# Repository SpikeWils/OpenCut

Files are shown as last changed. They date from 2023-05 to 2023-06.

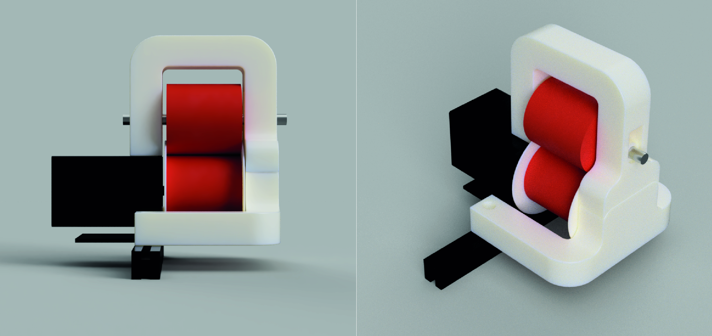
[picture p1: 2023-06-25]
OpenCut Src & Docs/OpenCut Docs/3D Printing Files/Feed Motor Assembly Renders.jpg

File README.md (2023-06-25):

# OpenCut

OpenCut is an open-source project aimed at developing an automated cable processing machine. It is designed to measure, cut cables to length, and print a cable ID directly onto the cable. Currently, the project is in its infancy, and only a prototype machine has been constructed. However, the project has the vision to continue development and cultivate a flexible and innovative solution to automated cable processing for wiring looms and harnesses. The intent is to foster a community to contribute to and further the development of the project.

The project includes two main components: MAS (Manufacturing Automation Software) and Machine Software.

## Directory Structure

The repository is divided into two main directories: `OpenCut Src` and `OpenCut Docs`.

### Source Code

The `OpenCut Src` directory contains the source code of the project and is divided into two sub-directories:

- `OpenCut MAS Software`: This directory contains the code for the MAS component of the OpenCut project. The MAS is the interface between the operator and the machine, allowing data about different cable types to be added, stored, modified, etc. It also saves machine parameters. It is designed to be executed on a desktop computer but can also be run on an SBC like a Raspberry Pi.
- `OpenCut Machine Software`: This directory contains the code for the Machine software component of the OpenCut project. This software is to be flashed onto the microcontroller embedded in the OpenCut machine.

### Documentation

The `OpenCut Docs` directory contains various forms of documentation and resources related to the project, including:

- `3D Printing Files`: This directory contains files related to 3D printing parts for the OpenCut project.
- `Functional Flow Charts`: This directory contains flowcharts that explain the functional flow of the OpenCut hardware and software.
- `Laser Cutting Files`: This directory contains files related to laser cutting parts for the OpenCut project.
- `Schematics`: This directory contains schematics related to the OpenCut project.

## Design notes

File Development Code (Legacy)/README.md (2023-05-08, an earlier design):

# Cable Machine
 
Abbreviations
-------------------------
  FM = Feed Motor
  CM = Cut Motor
  ENA = Enable
  DIR = Direction
  PUL = Pulse (A.K.A Step)
  CW = Clockwise
  CCW = Counter Clockwise

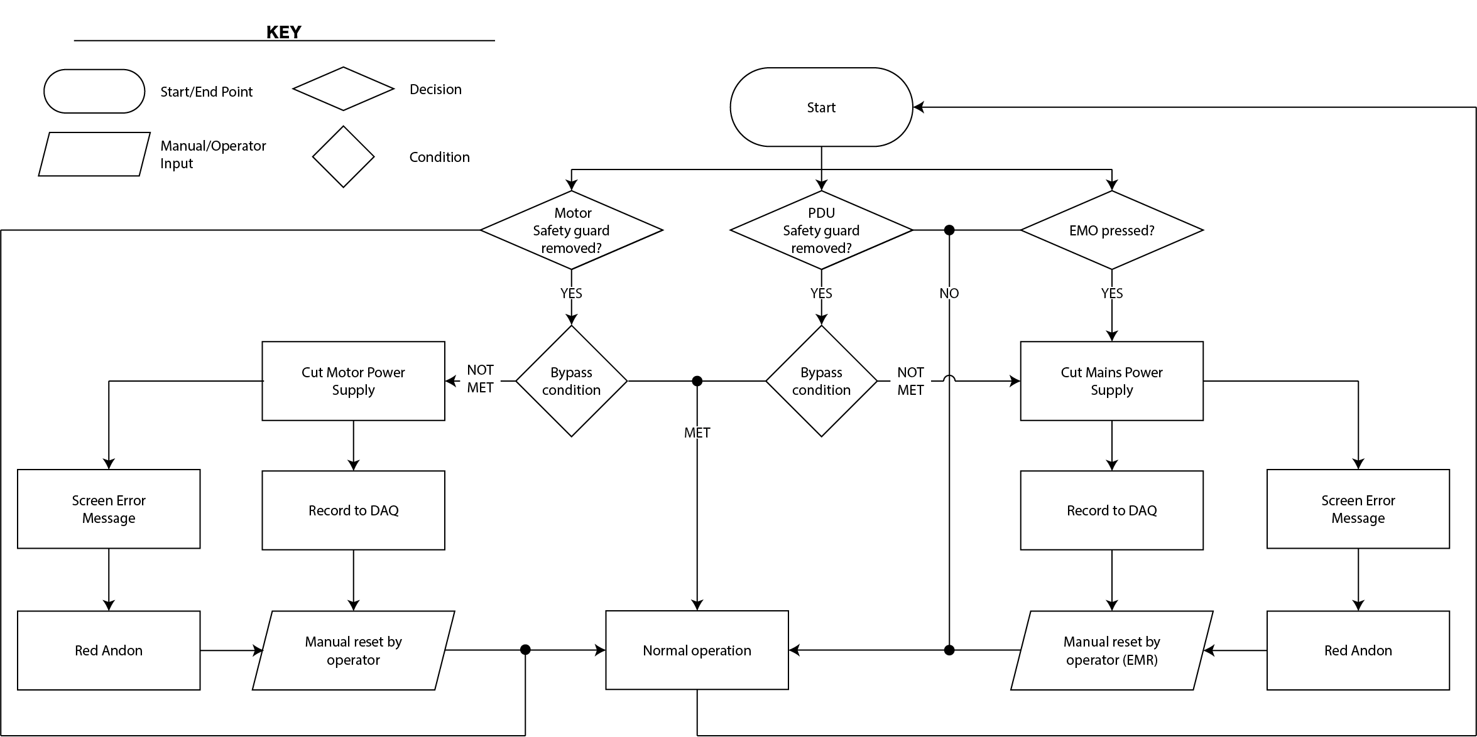
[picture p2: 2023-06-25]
OpenCut Src & Docs/OpenCut Docs/Functional Flow Charts/Hardware Safety System.png

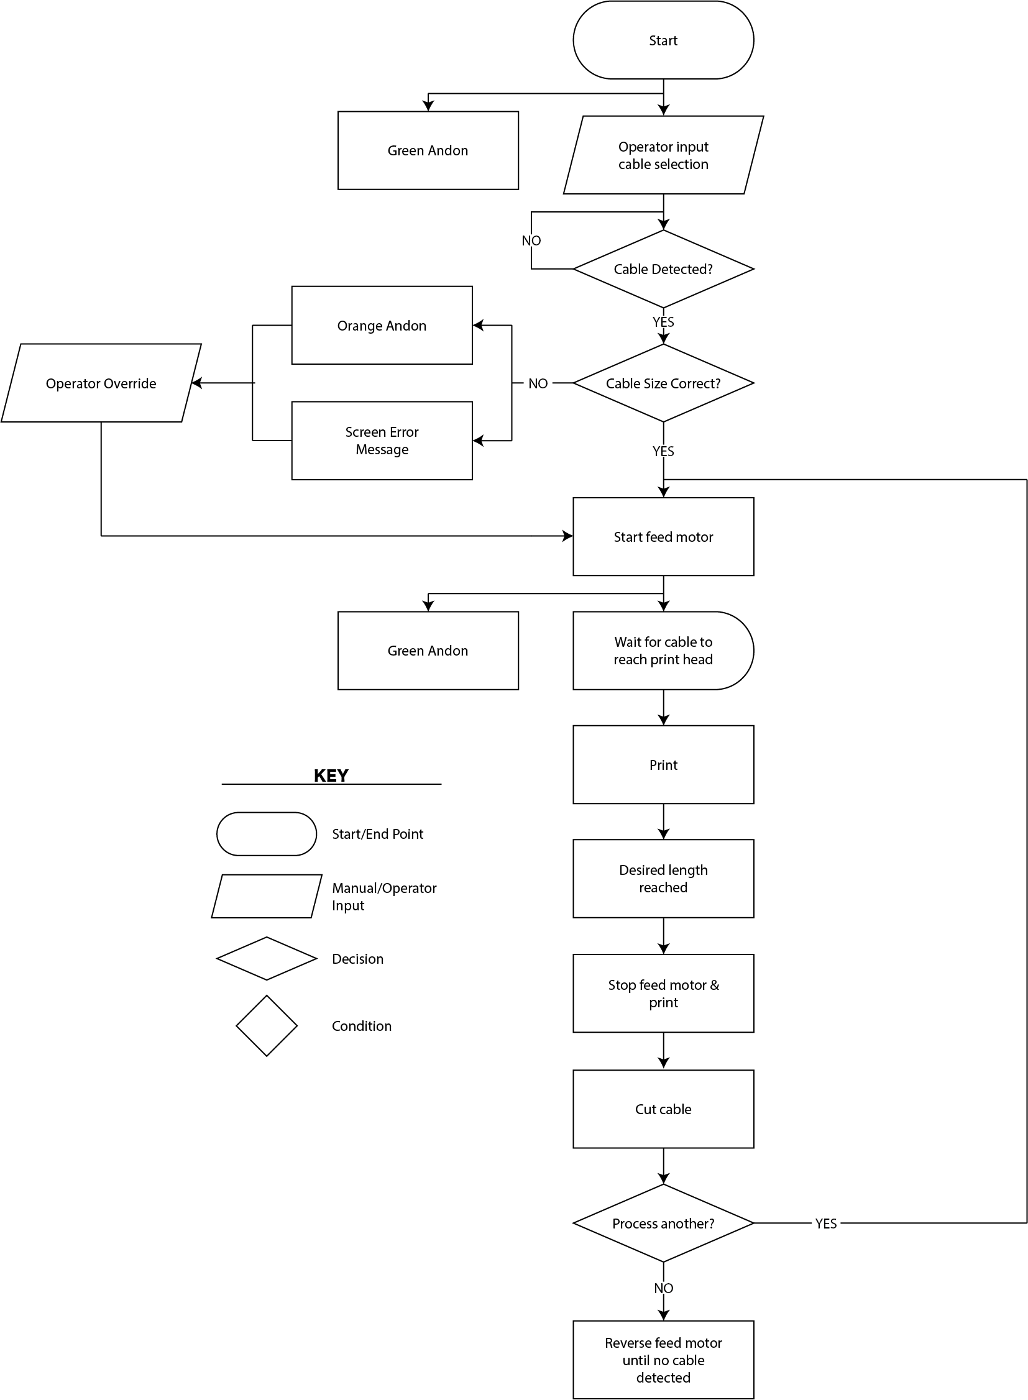
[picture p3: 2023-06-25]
OpenCut Src & Docs/OpenCut Docs/Functional Flow Charts/MCU Simplified.png

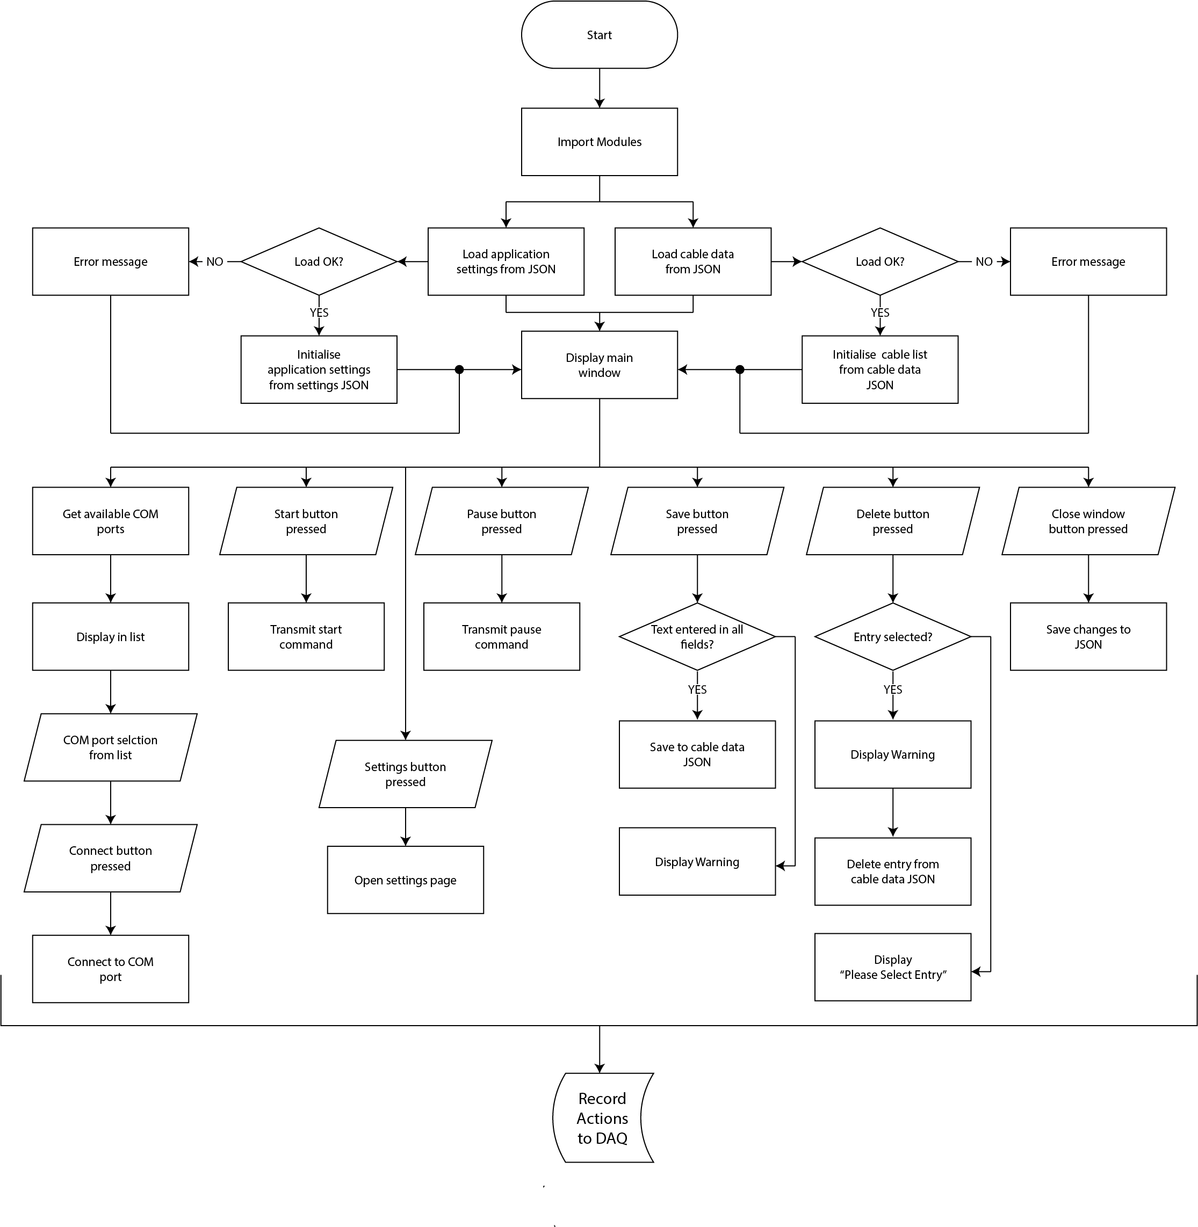
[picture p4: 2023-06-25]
OpenCut Src & Docs/OpenCut Docs/Functional Flow Charts/MAS Simplified.png

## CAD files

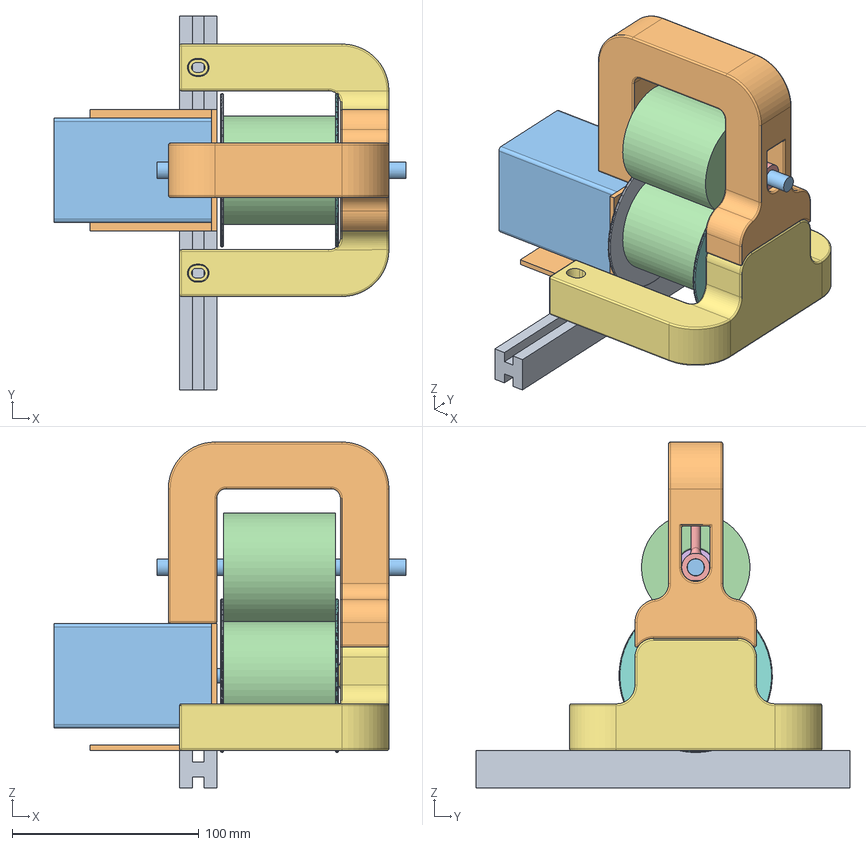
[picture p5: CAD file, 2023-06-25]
OpenCut Src & Docs/OpenCut Docs/3D Printing Files/Feed Motor Assembly.step
188.0 x 200.0 x 185.0 mm

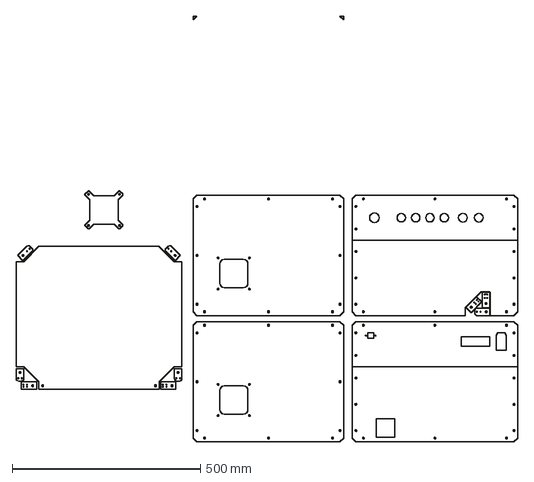
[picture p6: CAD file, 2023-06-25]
OpenCut Src & Docs/OpenCut Docs/Laser Cutting Files/Laser Cut Panel Vectors.dxf
1332.0 x 1131.5 mm

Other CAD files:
OpenCut Src & Docs/OpenCut Docs/3D Printing Files/Feed Motor Assembly 3D Model.f3d

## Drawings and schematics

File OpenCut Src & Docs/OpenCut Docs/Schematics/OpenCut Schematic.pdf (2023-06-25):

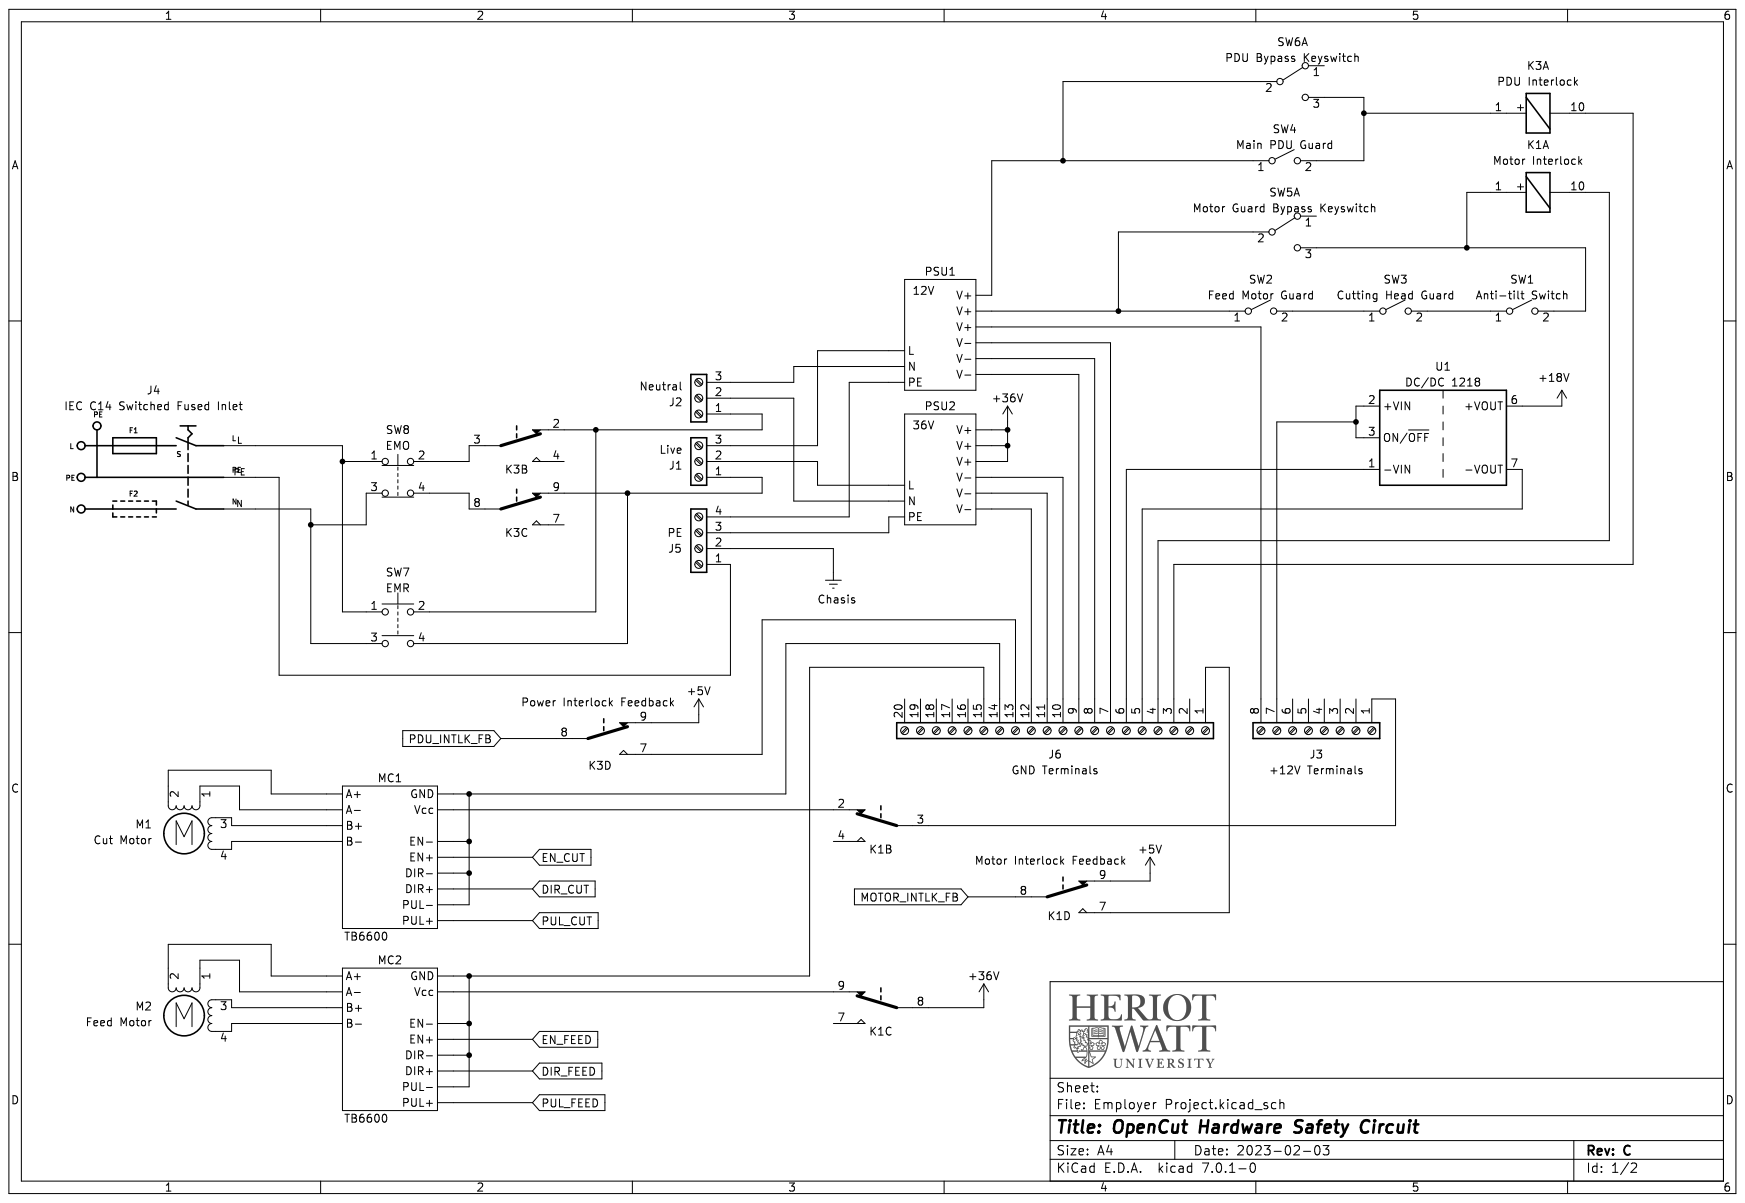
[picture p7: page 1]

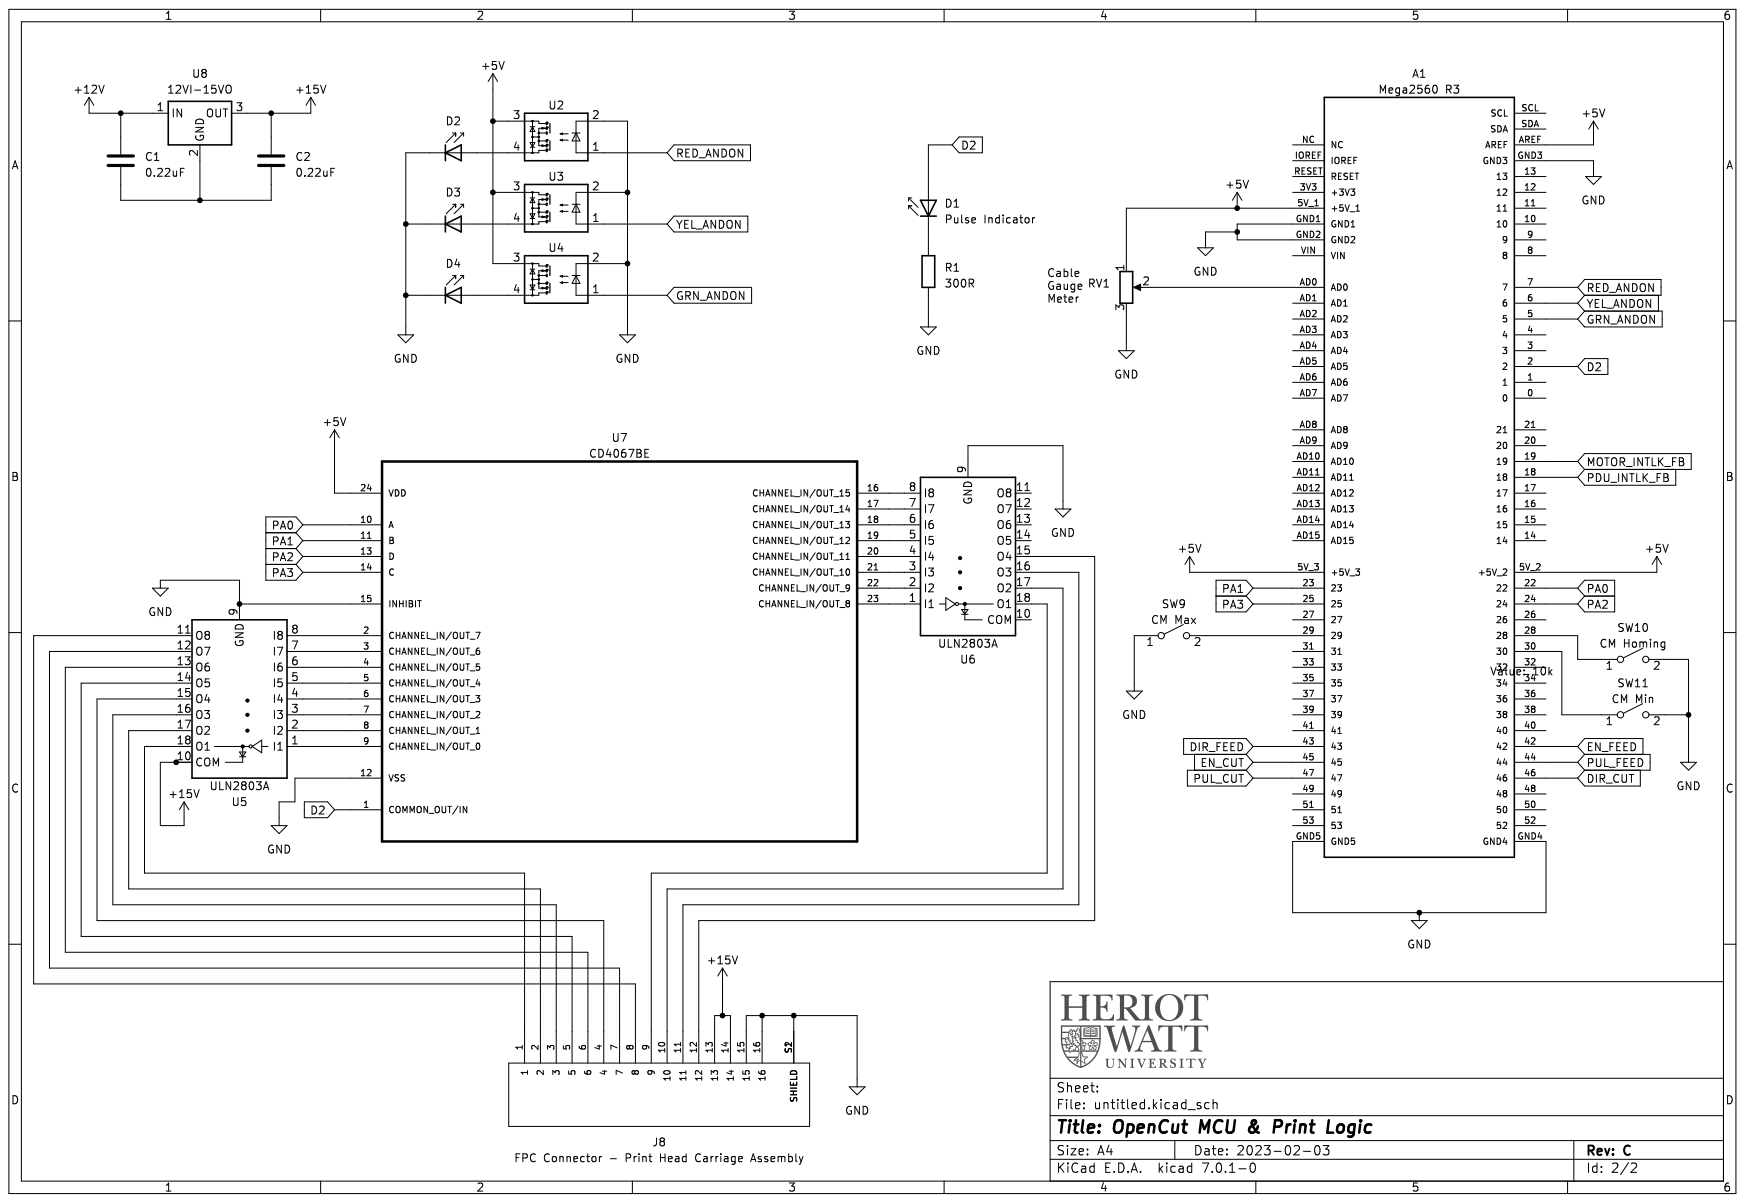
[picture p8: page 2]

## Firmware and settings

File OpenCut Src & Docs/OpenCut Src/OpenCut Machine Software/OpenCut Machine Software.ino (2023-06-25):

/*
    ▄██████▄     ▄███████▄    ▄████████ ███▄▄▄▄    ▄████████ ███    █▄      ███
   ███    ███   ███    ███   ███    ███ ███▀▀▀██▄ ███    ███ ███    ███ ▀█████████▄
   ███    ███   ███    ███   ███    █▀  ███   ███ ███    █▀  ███    ███    ▀███▀▀██
   ███    ███   ███    ███  ▄███▄▄▄     ███   ███ ███        ███    ███     ███   ▀
   ███    ███ ▀█████████▀  ▀▀███▀▀▀     ███   ███ ███        ███    ███     ███
   ███    ███   ███          ███    █▄  ███   ███ ███    █▄  ███    ███     ███
   ███    ███   ███          ███    ███ ███   ███ ███    ███ ███    ███     ███
    ▀██████▀   ▄████▀        ██████████  ▀█   █▀  ████████▀  ████████▀     ▄████▀


|----------------------------------------------------------------------------------------------------------------------------------------------------------------|
| Abbreviations and Acronyms:                                                                                                                                    |
|----------------------------------------------------------------------------------------------------------------------------------------------------------------|
|                                                                                                                                                                |
| ADC   = Analog to Digital Converter: A device that converts analog signals into digital numbers.                                                               |
| ANDON = Andon System: A manufacturing term referring to a system notifying management, maintenance, and other workers of a quality or process problem.         |
| CCW   = Counterclockwise: Referring to a counterclockwise rotation or movement.                                                                                |
| CM    = Cut Motor: Referring to the cutting motor in the machine.                                                                                              |
| CW    = Clockwise: Referring to a clockwise rotation or movement.                                                                                              |
| D2S   = Distance to Steps: The conversion factor from distance to steps for a motor.                                                                           |
| DIR   = Direction: Used for the direction signal pin on the motor drivers, controlling motor rotation direction.                                               |
| ENA   = Enable: Used for the enable signal pin on the motor drivers, activating or deactivating the motor.                                                     |
| FM    = Feed Motor: Referring to the feeding motor in the machine.                                                                                             |
| GRN   = Green: Referring to the color of an LED or signal lamp.                                                                                                |
| ID    = Identifier: A unique identification for cables.                                                                                                        |
| intlk = Interlock: A mechanism ensuring that certain conditions are met before actions are executed.                                                           |
| ISR   = Interrupt Service Routine: A function that handles the actions required at the time of an interrupt.                                                   |
| PDU   = Power Distribution Unit: Subsystem providing control and distribution of electric power.                                                               |
| PUL   = Pulse: Used for the pulse signal pin on the motor drivers, controlling motor steps.                                                                    |
| RED   = Red: Referring to the color of an LED or signal lamp.                                                                                                  |
| YEL   = Yellow: Referring to the color of an LED or signal lamp.                                                                                               |
|                                                                                                                                                                |
|----------------------------------------------------------------------------------------------------------------------------------------------------------------|



╔═══════════════════════════════════════════════════════════════════════════════════════════════════╗
║                          TB6600 STEPPER MOTOR DRIVER DIP SWITCH SETTINGS                          ║
╠═════╦═════╦═════╦═══════════════╦═══════════╦══╦═════╦═════╦═════╦═════════════╦══════════════════╣
║  S1 ║  S2 ║  S3 ║ µStep Setting ║ Pulse/Rev ║  ║  S4 ║  S5 ║  S6 ║ CURRENT (A) ║ PEAK CURRENT (A) ║
╠═════╬═════╬═════╬═══════════════╬═══════════╣  ╠═════╬═════╬═════╬═════════════╬══════════════════╣
║  ON ║  ON ║  ON ║       NC      ║     NC    ║  ║  ON ║  ON ║  ON ║     0.5     ║        0.7       ║
╠═════╬═════╬═════╬═══════════════╬═══════════╣  ╠═════╬═════╬═════╬═════════════╬══════════════════╣
║  ON ║  ON ║ OFF ║   FULL STEP   ║    200    ║  ║  ON ║ OFF ║  ON ║     1.0     ║        1.2       ║
╠═════╬═════╬═════╬═══════════════╬═══════════╣  ╠═════╬═════╬═════╬═════════════╬══════════════════╣
║  ON ║ OFF ║  ON ║    1/2 STEP   ║    400    ║  ║  ON ║  ON ║ OFF ║     1.5     ║        1.7       ║
╠═════╬═════╬═════╬═══════════════╬═══════════╣  ╠═════╬═════╬═════╬═════════════╬══════════════════╣
║ OFF ║  ON ║  ON ║    1/2 STEP   ║    400    ║  ║  ON ║ OFF ║ OFF ║     2.0     ║        2.2       ║
╠═════╬═════╬═════╬═══════════════╬═══════════╣  ╠═════╬═════╬═════╬═════════════╬══════════════════╣
║  ON ║ OFF ║ OFF ║    1/4 STEP   ║    800    ║  ║ OFF ║  ON ║  ON ║     2.5     ║        2.7       ║
╠═════╬═════╬═════╬═══════════════╬═══════════╣  ╠═════╬═════╬═════╬═════════════╬══════════════════╣
║ OFF ║  ON ║ OFF ║    1/8 STEP   ║    1600   ║  ║ OFF ║ OFF ║  ON ║     2.8     ║        2.9       ║
╠═════╬═════╬═════╬═══════════════╬═══════════╣  ╠═════╬═════╬═════╬═════════════╬══════════════════╣
║ OFF ║ OFF ║  ON ║   1/16 STEP   ║    3200   ║  ║ OFF ║  ON ║ OFF ║     3.0     ║        3.2       ║
╠═════╬═════╬═════╬═══════════════╬═══════════╣  ╠═════╬═════╬═════╬═════════════╬══════════════════╣
║ OFF ║ OFF ║ OFF ║   1/32 STEP   ║    6400   ║  ║ OFF ║ OFF ║ OFF ║     3.2     ║        4.0       ║
╚═════╩═════╩═════╩═══════════════╩═══════════╩══╩═════╩═════╩═════╩═════════════╩══════════════════╝


  Feed Motor Driver Settings (Current)
  -------------------------------------
  S1 = ON       - FULL STEP
  S2 = ON
  S3 = OFF
  S4 = ON       - 1.5 Amps
  S5 = ON
  S6 = OFF

  Distance to steps factor
  -------------------------
  Roller Diameter       = 58mm
  Roller Circumference  = 182.2124mm
  1mm Linear travel     = 0.506°  = 0.281 steps
  1m Linear travel      = 506°    = 281 steps 

  (πd / 360) / step angle * µstep = steps per 1mm of linear travel

  d = roller diameter
  step angle = full step angle of motor
  µstep = divisor


  Cut Motor Driver Settings (Current)
  -------------------------------------
  S1 = OFF      - 1/8 STEP
  S2 = ON
  S3 = OFF
  S4 = OFF       - 2.5 Amps
  S5 = ON
  S6 = ON


  Cut Motor Linear Travel Calculation
  -------------------------------------

                    Steps per turn x microstep setting
  Steps per mm = ────────────────────────────────────── x gear ratio
                              Screw pitch
                                                                                                                                               
 */

/**********************************************************************************************************
   INCLUDES
**********************************************************************************************************/

#include <Arduino.h>                                  //Import the Arduino library (necessary for non Arduino MCUs)
#include <AccelStepper.h>                             //https://github.com/waspinator/AccelStepper
#include "CableIDPrinter.h"                           //

/**********************************************************************************************************
   DEFINE PINS
**********************************************************************************************************/

#define FM_ENA_PIN 42                                 //Define pin number for motor controller enable pin
#define FM_DIR_PIN 43                                 //Define pin number for motor controller direction pin
#define FM_PUL_PIN 44                                 //Define pin number for motor controller pulse/step pin

#define CM_ENA_PIN 45                                 //Define pin number for motor controller enable pin
#define CM_DIR_PIN 46                                 //Define pin number for motor controller direction pin
#define CM_PUL_PIN 47                                 //Define pin number for motor controller pulse/step pin

#define CM_HOME_SWITCH_PIN 28                         //Define pin number for homing switch (N.O)
#define CM_LIMIT_SWITCH_MAX_PIN 29                    //Define pin number for maximum R.O.M limit switch
#define CM_LIMIT_SWITCH_MIN_PIN 30                    //Define pin number for minimum R.O.M limit switch

#define PRINTER_PIN 2                                 //Define pin number for print head controller pulse
                                                      //  !!! CAUTION !!! - Pins A0>A3 must be kept free for print head data

#define RED_ANDON_PIN 7                               //Define pin to control andon light
#define YEL_ANDON_PIN 8                               //Define pin to control andon light
#define GRN_ANDON_PIN 9                               //Define pin to control andon light

#define CABLE_DETECTION_PIN 54                        //Define pin which cable detection device is connected (must be ADC pin)

#define PDU_INTLK_PIN 18                              //Define PDU interlock pin (Must be interrupt enabled)
#define MOT_INTLK_PIN 19                              //Define Motor interlock pin (Must be interrupt enabled)

/**********************************************************************************************************
   DEFINE PARAMETERS
**********************************************************************************************************/

#define FM_MAX_SPEED 1000                             //Define maximum motor speed value
#define FM_MAX_ACCEL 1000                             //Define maximum motor acceleration value

#define CM_MAX_SPEED 1000                             //Define maximum motor speed value
#define CM_MAX_ACCEL 1000                             //Define maximum motor acceleration value

#define FM_CIRCUMFERENCE 182.2                        //Define circumference of feed roller
#define FM_STEP_ANGLE 1.8                             //Define step angle of motor  >>SEE NOTE BELOW<<
#define FM_MICROSTEP_SETTING 8                        //Define the microstep setting of the motor controller

#define CM_STEP_ANGLE 1.8                              //Define step angle of motor
#define CM_MICROSTEP_SETTING 1                         //Define the microstep setting of the motor controller >>SEE NOTE BELOW<<
#define CM_GEAR_RATIO 49                               //Define gear ratio 1:49
#define CM_SCREW_PITCH 2                               //Define lead screw pitch in mm

/*
╔═══════════════════════════════════════════════╗
║                      NOTE                     ║
║ Microstep setting value determined as follows ║
╠═══════════════════════════╦═══════════════════╣
║         Full step         ║         1         ║
╠═══════════════════════════╬═══════════════════╣
║          1/2 step         ║         2         ║
╠═══════════════════════════╬═══════════════════╣
║          1/4 step         ║         4         ║
╠═══════════════════════════╬═══════════════════╣
║          1/8 step         ║         8         ║
╠═══════════════════════════╬═══════════════════╣
║         1/16 step         ║         16        ║
╠═══════════════════════════╬═══════════════════╣
║         1/32 step         ║         32        ║
╚═══════════════════════════╩═══════════════════╝
*/

#define FM_D2S_FACTOR FM_CIRCUMFERENCE / FM_STEP_ANGLE * FM_MICROSTEP_SETTING                             //Defines the distance to steps factor

#define CM_STEPS_PER_TURN CM_STEP_ANGLE*360                                                               //Calculate number of steps per full turn of motor
#define CM_S2L_FACTOR ((CM_STEPS_PER_TURN * CM_MICROSTEP_SETTING) / CM_SCREW_PITCH) * CM_GEAR_RATIO       //Calculate number of steps per 1mm linear travel of carriage


/**********************************************************************************************************
   DECLARE VARIABLES & CONSTANTS
**********************************************************************************************************/

String cableID;                                       //Declare a string variable to store the cable ID
int cableLength;                                      //Declare an integer variable to store the cable length
int cableGauge;                                       //Declare an integer variable to store the cable gauge
int distance = 0;                                     //Declare variable to store distance feed roller has moved
bool newData = false;                                 //Declare and initialize a boolean flag for new data received
bool paused = false;                                  //Declare and initialize a boolean flag for the paused state
bool gaugeMatch = false;                              //Declare flag to indicate if the cable gauge values match within the range.
bool pduMessagePrinted = false;                       //Declare flag to indicate if PDU interlock message has been sent
bool motorMessagePrinted = false;                     //Declare flag to indicate if motor interlock message has been sent
volatile bool pduInterlock = false;                   //Declare flag to indicate if PDU interlock is engaged
volatile bool motorInterlock = false;                 //Declare flag to indicate if motor interlock is engaged

int CM_homing_pos = 0;                                //Declare global variable for homing position
int cutPosition = 100;                                //Length of travel of linear actuator for cut motor (final position of blade after cutting)
int releasePosition = -350;                           //Distance to move cable in reverse to release from feed rollers

const int PDU_Intlk = PDU_INTLK_PIN;                  //Pin connected to PDU interlock signal
const int Motor_Intlk = MOT_INTLK_PIN;                //Pin connected to Motor interlock signal

/**********************************************************************************************************
   DECLARE OBJECTS
**********************************************************************************************************/

AccelStepper FeedMotor(AccelStepper::DRIVER, FM_PUL_PIN, FM_DIR_PIN);     //Create class for feed motor
AccelStepper CutMotor(AccelStepper::DRIVER, CM_PUL_PIN, CM_DIR_PIN);      //Create class for cut motor

CableIDPrinter printer(PRINTER_PIN);                                      //Create printer class initialize on printer pin


/*────────────────────────────────────────────────────────────────────────────
   CM STARTUP HOMING POSITION
────────────────────────────────────────────────────────────────────────────*/

void CM_startup_homing_sequence()                     //Declare function for homing cut motor at startup
{
  CutMotor.setEnablePin(CM_ENA_PIN);                  //Declare feed motor enable pin [Must be manually declared when using driver type in class]
  CutMotor.setPinsInverted(false, false, true);       //Invert the logic of the enable pin (step, direction, enable)
  CutMotor.setMaxSpeed(CM_MAX_SPEED);                 //Set speed = steps/second
  CutMotor.setAcceleration(CM_MAX_ACCEL);             //Set acceleration = steps/(second)^2
  CutMotor.enableOutputs();                           //Enable outputs on motor controller (allow current flow to motor)

  Serial.println("Cut motor homing...");              //Print to serial monitor

  while(digitalRead(CM_HOME_SWITCH_PIN))              //Rotate CCW until homing switch is pressed
  {
    CutMotor.moveTo(CM_homing_pos);                   //Move cut motor to homing position
    CM_homing_pos--;                                  //Decrement homing position
    CutMotor.run();                                   //Run cut motor
    delay(50);                                        //Delay 50ms to prevent motor stepping too fast and causing damage
  }

  CM_homing_pos = 1;
  CutMotor.setCurrentPosition(0);                     //Set home position to zero
  

  while(!digitalRead(CM_HOME_SWITCH_PIN))             //Rotate CW until homing switch is not pressed
  {
    CutMotor.moveTo(CM_homing_pos);                   //Move cut motor to homing position
    CM_homing_pos++;                                  //Increment homing position
    CutMotor.run();                                   //Run cut motor
    delay(50);                                        //Delay 50ms to prevent motor stepping too fast and causing damage
  }  

  CutMotor.setCurrentPosition(0);                     //Set home position to zero
  CutMotor.disableOutputs();                          //Prevent current flow to motor (prevents overheating)

  Serial.print("Cut Motor Position: ");               //Print to serial monitor
  Serial.print(CM_homing_pos);                        //Print value of homing position to serial monitor (must always be zero)
}


/*────────────────────────────────────────────────────────────────────────────
   CABLE GAUGE CHECK
────────────────────────────────────────────────────────────────────────────*/

void checkGaugeMatch(int cableGauge)                  //Check inserted cable matches gauge declared by MAS application
{
  int potValue = analogRead(CABLE_DETECTION_PIN);     //Read the ADC value (0 to 1023).
   
  int mappedValue = map(potValue, 0, 1023, 2, 25);    // Map the ADC reading to the range 2mm to 25mm.

  if (abs(mappedValue - cableGauge) <= 1)             //Compare the mapped value with cableGauge If the values are within plus or minus 1mm, set gaugeMatch to true, else false
  {
    gaugeMatch = true;
  }
    
  else                                                //Otherwise set the gaugematch flag to false and light yellow andon
  {
    gaugeMatch = false;
    digitalWrite(GRN_ANDON_PIN, LOW);
    digitalWrite(RED_ANDON_PIN, LOW);
    digitalWrite(YEL_ANDON_PIN, HIGH);
  }
}

/*────────────────────────────────────────────────────────────────────────────
   OVERRIDE GAUGE MISMATCH
────────────────────────────────────────────────────────────────────────────*/

void overrideGaugeMatch()                             //Operator override cable gauge mismatch
{
  if (Serial.available() > 0)                         //If data in serial buffer
  {
    String inputString = Serial.readString();         //Read the input string from Serial Monitor.

    inputString.trim();                               //Trim the input string.

    if (inputString == "override")                    //Check if the input string is "override"
    {
      gaugeMatch = true;                              //Manually set gaugeMatch to true.
      digitalWrite(GRN_ANDON_PIN, HIGH);              //Light green andon
      digitalWrite(RED_ANDON_PIN, LOW);
      digitalWrite(YEL_ANDON_PIN, LOW);
    }
  }
}
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
void loop()
{
  checkAndPrintPduInterlock();                        //Call PDU Interlock Function
  checkAndPrintMotorInterlock();                      //Call motor Interlock Function
  readSerialData();                                   //Call read serail data function
  printCableData();                                   //Call print cable data function
  checkGaugeMatch(cableGauge);                        //Call check gauge match function

  if (gaugeMatch)                                     //If cable gauge matches
  {
    Serial.println("Gauge OK!");                      //Send message
  }

  else                                                //Otherwise
  {
    Serial.println("WARNING: Gauge Mismatch!");       //Send message
    digitalWrite(YEL_ANDON_PIN, HIGH);                //Light yellow andon
    overrideGaugeMatch();                             //Call override gauge match function
  }

  if (!paused && newData && gaugeMatch)               //If the system is not paused, new data is available, and the gauge matches
  {
    moveFeedMotor(cableLength);                       //Move the feed motor based on the cable length
    moveCutMotor();                                   //Call move cut motor function

    FeedMotor.enableOutputs();                        //Enable motor outputs for the feed motor
    FeedMotor.setCurrentPosition(0);                  //Set the current motor position of the feed motor to 0
    FeedMotor.moveTo(releasePosition);                //Move the feed motor to the release position

    while (FeedMotor.isRunning())                     //Continue running the feed motor until it reaches the release position
    {
      FeedMotor.run();                                //Execute feed motor movement
    }

    FeedMotor.disableOutputs();                       //Disable motor outputs for the feed motor (Prevents overheating)
    delay(1000);                                      //Wait 1 second
    FeedMotor.setCurrentPosition(0);                  //Set the current motor position of the feed motor back to 0

    newData = false;                                  //Reset the newData flag to indicate that the data has been processed
  }
}

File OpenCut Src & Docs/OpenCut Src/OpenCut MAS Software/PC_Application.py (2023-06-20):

#  ▄██████▄     ▄███████▄    ▄████████ ███▄▄▄▄    ▄████████ ███    █▄      ███
# ███    ███   ███    ███   ███    ███ ███▀▀▀██▄ ███    ███ ███    ███ ▀█████████▄
# ███    ███   ███    ███   ███    █▀  ███   ███ ███    █▀  ███    ███    ▀███▀▀██
# ███    ███   ███    ███  ▄███▄▄▄     ███   ███ ███        ███    ███     ███   ▀
# ███    ███ ▀█████████▀  ▀▀███▀▀▀     ███   ███ ███        ███    ███     ███
# ███    ███   ███          ███    █▄  ███   ███ ███    █▄  ███    ███     ███
# ███    ███   ███          ███    ███ ███   ███ ███    ███ ███    ███     ███
#  ▀██████▀   ▄████▀        ██████████  ▀█   █▀  ████████▀  ████████▀     ▄████▀
#
#
# *****************************************************
#  IMPORT MODULES
# *****************************************************

import os
import sys
import serial
from PyQt5.QtWidgets import *
from PyQt5.QtCore import *
from PyQt5.QtGui import *
import datetime
import json
from serial.tools import list_ports

# ──────────────────────────────────────
#   GET AVAILABLE PORTS
# ──────────────────────────────────────

def get_available_ports():                                                      #Define function get_available_ports
    ports = list_ports.comports()                                               #List available COM ports and store in ports variable
    return [port.device for port in ports]                                      #Generate list from ports variable

# ──────────────────────────────────────
#   CABLE DATA
# ──────────────────────────────────────

class CableData:                                                                #Define class CableData
    def __init__(self, cable_id, length, cable_gauge):                          #Define cable data structure (cable_id, length, cable_gauge)
        self.cable_id = cable_id
        self.length = length
        self.cable_gauge = cable_gauge

    def to_string(self):                                                                                                    #Define function to_string for CableData class
        return "Cable ID: {}, Length: {}, Cable Gauge: {}".format(self.cable_id, self.length, self.cable_gauge)             #Return formatted data string of CableData class

# ──────────────────────────────────────
#   CABLE DATA WIDGET
# ──────────────────────────────────────

class CableDataWidget(QWidget):                                                 #Define class CableDataWidget
    def __init__(self, parent):                                                 #Define widget class constructor
        super().__init__()                                                      #Initialise widget

        self.parent = parent
        self.initUI()                                                           #Call initialise widget user interface

    def initUI(self):                                                           #Define function initUI
        self.cable_id_edit = QLineEdit(self)                                    #Create text input field
        self.cable_id_edit.setPlaceholderText('Cable ID')                       #Set placeholder text
        self.length_edit = QLineEdit(self)
        self.length_edit.setPlaceholderText('Length (mm)')
        self.cable_gauge_edit = QLineEdit(self)
        self.cable_gauge_edit.setPlaceholderText('Cable Gauge')

        save_button = QPushButton('Save', self)                                 #Create push button object with "Save" text
        save_button.clicked.connect(self.save_data)                             #Connect button clicked state to save data function

        layout = QVBoxLayout()                                                  #Arrange child objects in vertical column in order they appear below (set layout)
        layout.addWidget(self.cable_id_edit)                                    #Add cable ID text entry box
        layout.addWidget(self.length_edit)                                      #Add length text entry box
        layout.addWidget(self.cable_gauge_edit)                                 #Add cable gauge text entry box
        layout.addWidget(save_button)                                           #Add save button
        self.setLayout(layout)                                                  #Make CableDataWidget follow layout

    def save_data(self):                                                        #Define function save_data (Saves data entered in cable_id, length, cable_gauge fields)
        cable_id = self.cable_id_edit.text()                                    #Retrieve text from cable_id text entry box, store in variable cable_id
        length = self.length_edit.text()                                        #Retrieve text from length text entry box, store in variable length
        cable_gauge = self.cable_gauge_edit.text()                              #Retrieve text from cable_gauge text entry box, store in variable cable_gauge

        if cable_id and length and cable_gauge:                                 #If all three parameters have been entered:
            data = CableData(cable_id, length, cable_gauge)                     #Create new CableData object and assign to data variable
            self.parent.cable_data.append(data)                                 #Add data to cable_data list
            self.parent.update_cable_data_list()                                #Update the cable data list to show the new saved entry
            self.parent.save_cable_data()                                       #Save the cable data to the JSON file when new data is added
            self.cable_id_edit.clear()                                          #Clear contents of text entry box after data is saved
            self.length_edit.clear()                                            #Clear contents of text entry box after data is saved
            self.cable_gauge_edit.clear()                                       #Clear contents of text entry box after data is saved
        else:                                                                   #Otherwise:
            QMessageBox.warning(self, "Warning", "Please fill in all fields.")  #Display warning message

# ──────────────────────────────────────
#   APP SETTINGS WIDGET
# ──────────────────────────────────────
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

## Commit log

2023-04-30 Create FeedMotor.ino
    Created Feed Motor sketch, initialised basic parameters and basic commenting
2023-05-02 Create Cut Motor File
    Create cut motor file and declare basic variables & parameters
2023-05-05 Homing Function Added
    Homing on startup functionality added. Motor will rotate until homing switch pressed then set that position as home.
    Some additional comments and formatting added.
2023-05-05 Additional comments & CM Program Complete
    Additional informational comments in both motor programs. Cut motor program variables renamed and tested.
2023-05-05 CM Homing sequence packaged as function
    CM startup homing sequence packaged as discreet function. Additional formatting and comments
2023-05-06 Fixed errors in PC App
    PC app now remains open until manually closed. Time pulled from PC not arduino
2023-05-06 Filename change & GUI formatting
    Filename changed to prevent launch errors. Colours & formatting added to application GUI
    [PC_Application.py]
2023-05-07 Remove Screen & Update App
    Remove test screen code and added COM port selection to app, connect button and bug fixes.
    [PC_Application.py]
2023-05-07 COM Port Selection & Connect Buttons
    Added COM port selection & Connect button to initialise serial communication. Renamed some variables and formatting
2023-05-07 Cable Data Entry Fields Added
    Added entry fields for cable data. Fields not yet working.
2023-05-07 Fixed bug in .json read/write
    Missing lines to read/write to/from json file added. Cable data now saves and loads.
    [PC_Application.py]
2023-05-07 Remove NXT/PREV buttons
    Remove next and previous buttons as they are redundant
2023-05-07 Cable data delete button
    Added function for deleting data entries in cable data fields
2023-05-07 Execute Cable Data & Formatting
    Execute cable data on machine function added, minor formatting and button redefinitions.
2023-06-25 Folder Hierarchy Updated
    Updated folder hierarchy to ensure clarity in current and legacy files
    [Feed Motor Assembly 3D Model.f3d, Feed Motor Assembly.step, Laser Cut Panel Vectors.dxf]
